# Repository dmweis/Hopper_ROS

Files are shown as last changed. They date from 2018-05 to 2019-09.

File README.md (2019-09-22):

# ROS stack for a hexapod robot

## [Click here for more images](https://davidweis.dev/robotics/2019/09/21/HopperGallery2019.html)  

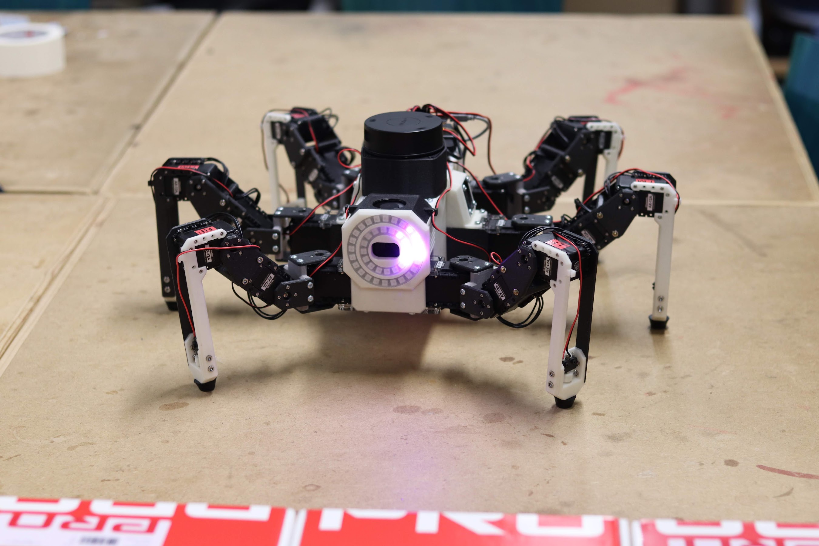
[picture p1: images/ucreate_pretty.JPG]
Hopper (https://davidweis.dev/robotics/2019/09/21/HopperGallery2019.html)
  

## [Click here to see live CAD model!](https://davidweis.dev/robotics/2019/06/22/HopperModels.html)  

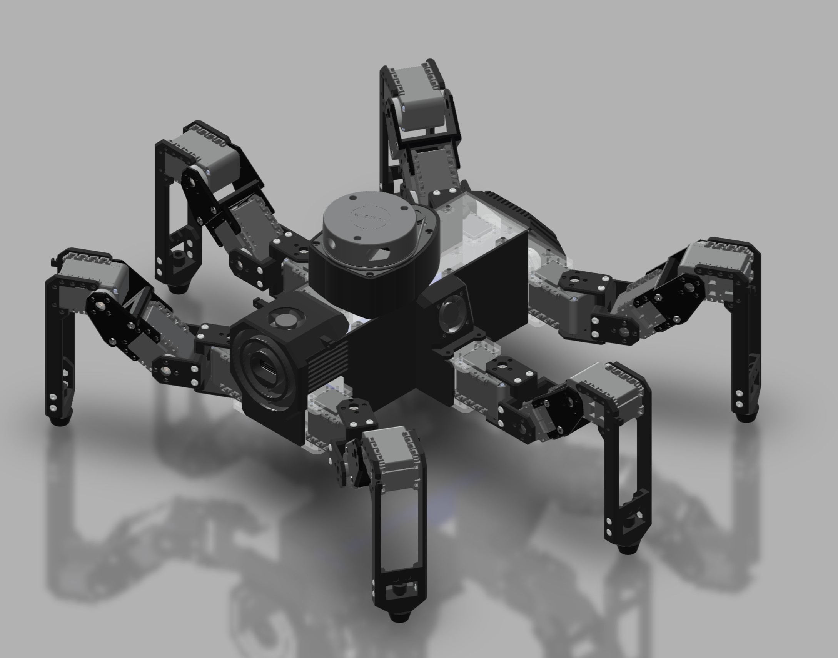
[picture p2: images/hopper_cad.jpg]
Cad model can be viewed here (https://davidweis.dev/robotics/2019/06/22/HopperModels.html)
  

## [Click here for videos](https://www.youtube.com/playlist?list=PL2rJqSX7Z5cFj5UM5ozf1wcm_McQg75ch)  

IMAGE ALT TEXT HERE (https://www.youtube.com/playlist?list=PL2rJqSX7Z5cFj5UM5ozf1wcm_McQg75ch)  

Hopper (Named after Grace Hopper) is a 3D printed hexapod robot running on ROS.
It's brain is a Raspberry Pi 3 running Ubunut Xenial with ROS Kinetic.
The platform is modeled and 3D printed by me and is still a work in progress. It's heavily inspired by [PhantomX Hexapod from Trossen robotics](http://www.trossenrobotics.com/phantomx-ax-hexapod.aspx)  

CAD design files can be found [here](https://github.com/dmweis/hopper_design)  
They may be outdated. If you'd like current file you can email me [here](mailto:dweis7@gmail.com)

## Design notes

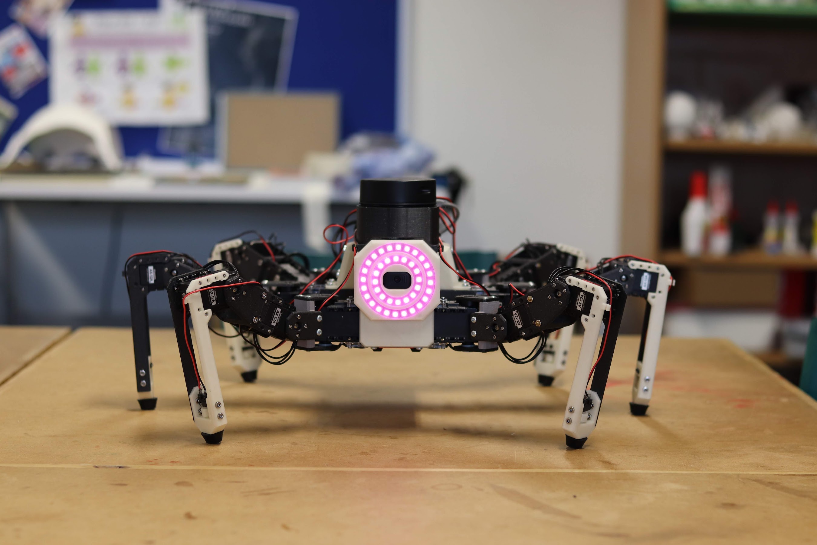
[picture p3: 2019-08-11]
images/ucreate_face.jpg

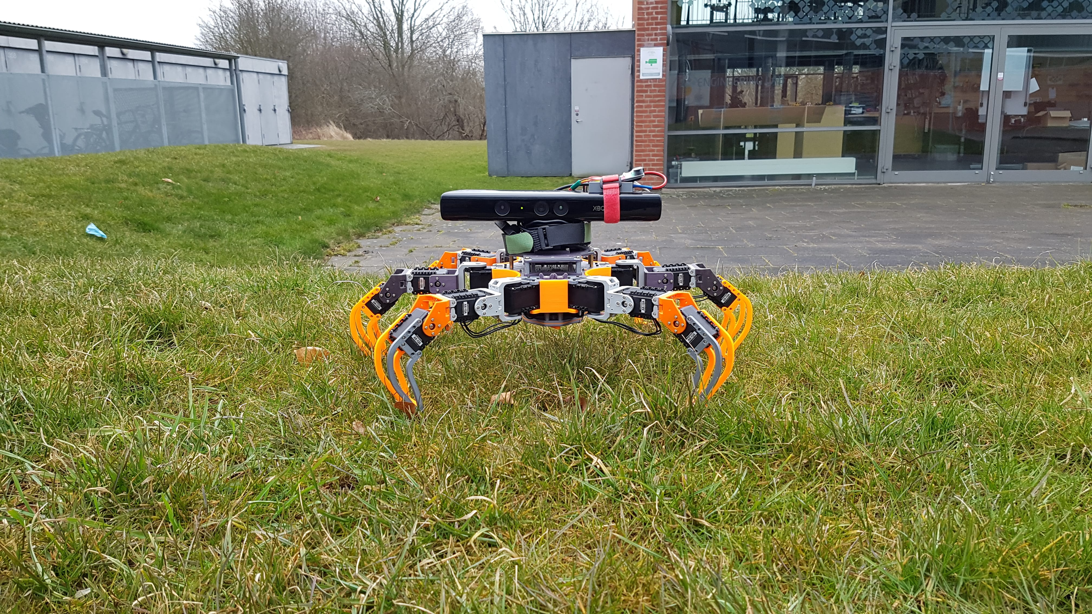
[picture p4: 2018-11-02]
images/grass_2.jpg

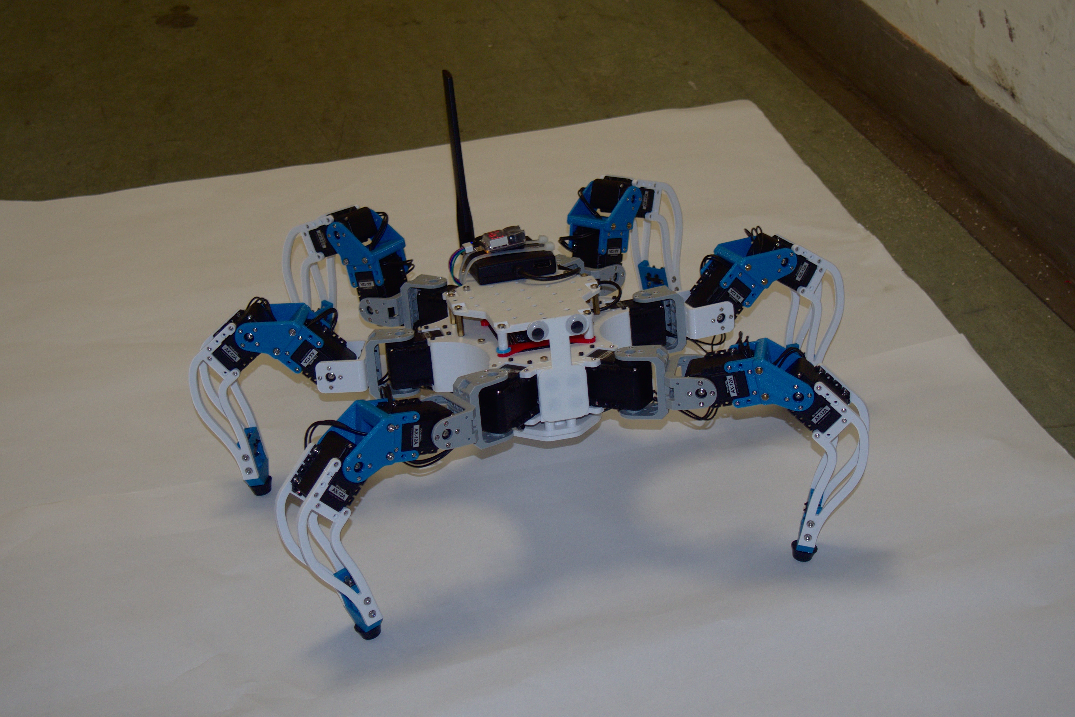
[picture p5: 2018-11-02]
images/last_2.jpg

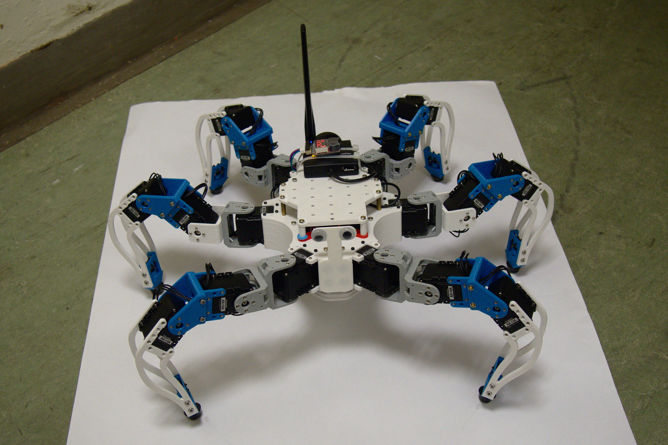
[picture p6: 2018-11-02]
images/last_1.jpg

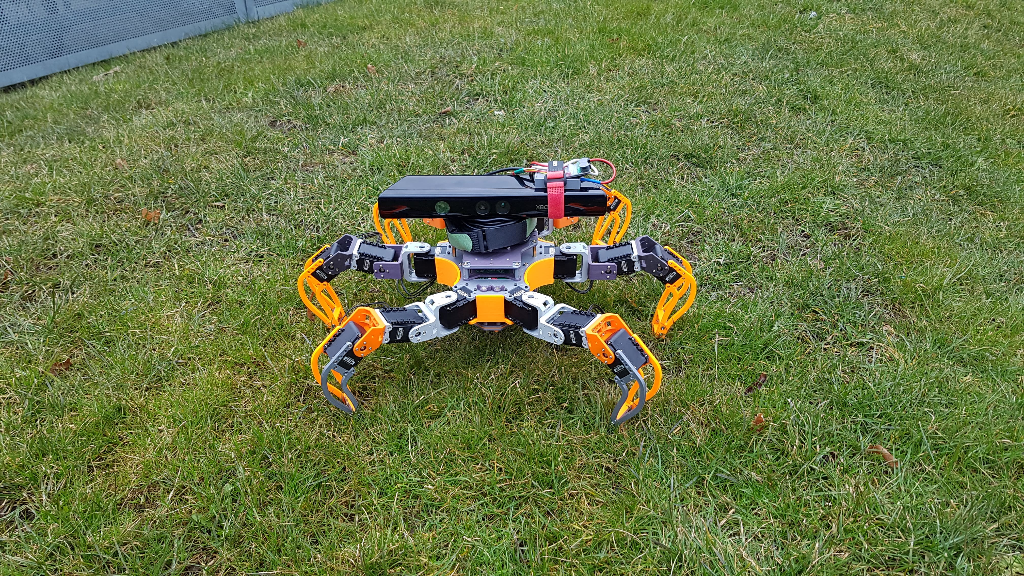
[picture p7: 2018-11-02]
images/grass_1.jpg

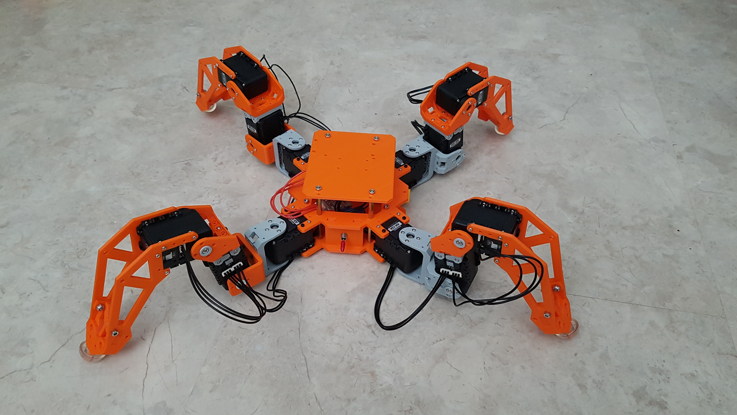
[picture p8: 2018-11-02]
images/quadruped.jpg

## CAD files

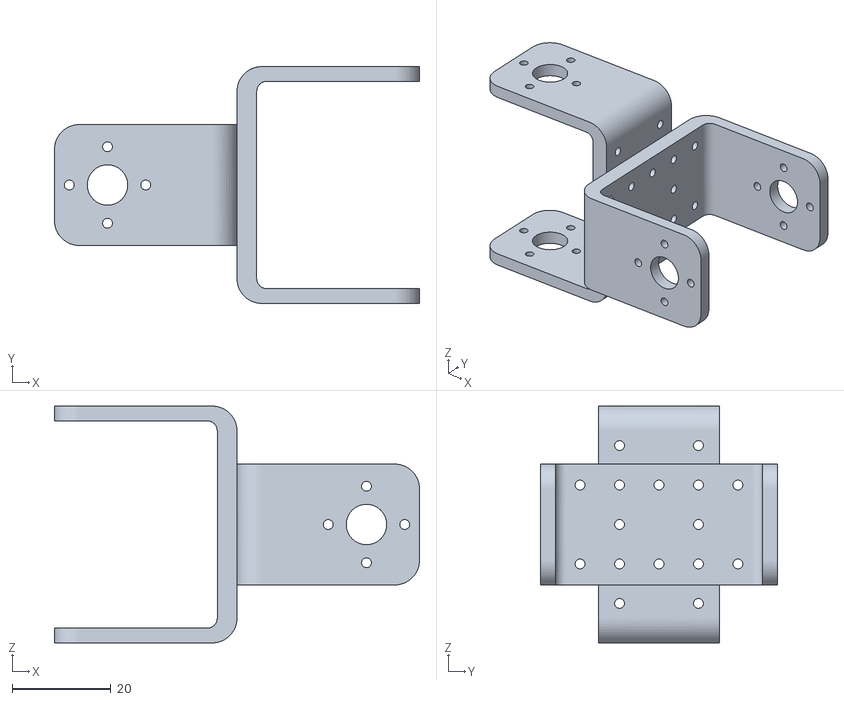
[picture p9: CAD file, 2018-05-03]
hopper_description/meshes/hopper_1/hopper_leg_coxa.stl
74.0 x 48.0 x 48.0

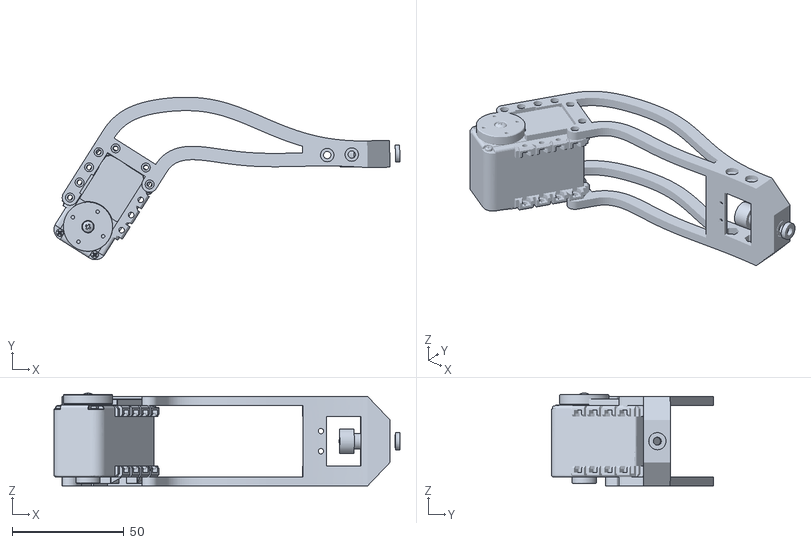
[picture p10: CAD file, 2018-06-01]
hopper_description/meshes/hopper_1/longer_legs/hopper_leg_tibia.stl
154.8 x 72.7 x 41.5

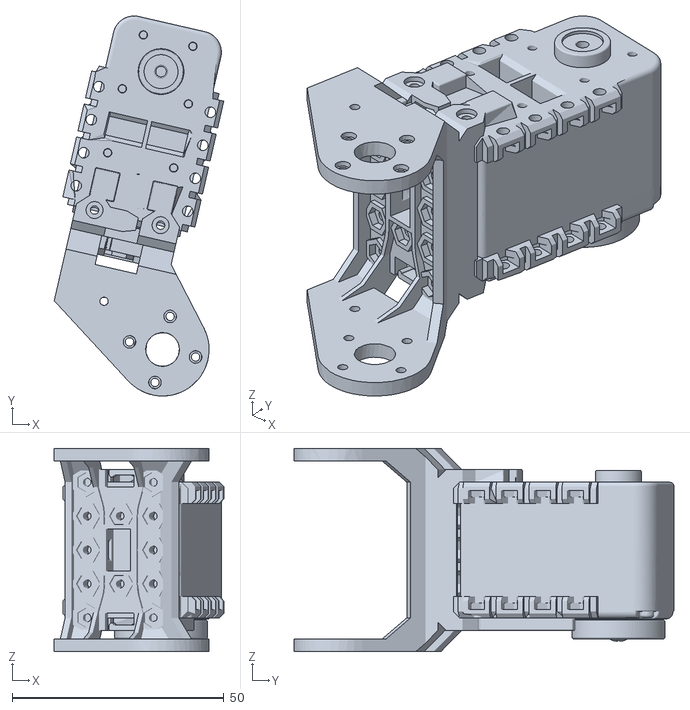
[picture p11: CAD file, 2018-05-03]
hopper_description/meshes/hopper_1/shorter_legs/hopper_leg_femur.stl
40.0 x 89.7 x 48.0

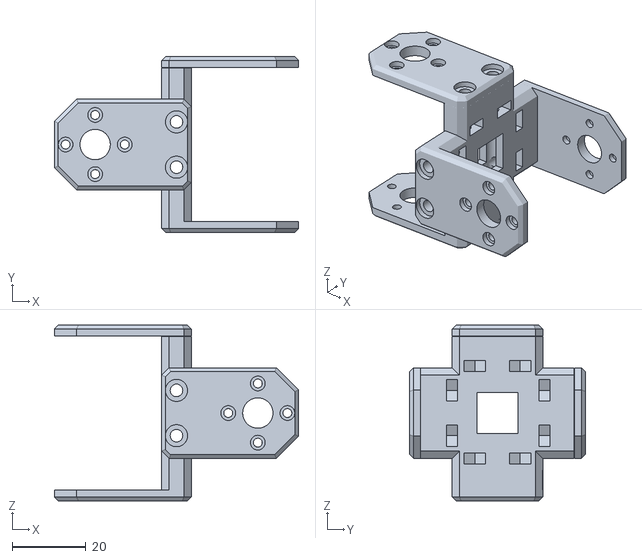
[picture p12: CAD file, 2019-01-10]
hopper_description/meshes/hopper_leg_coxa.stl
66.0 x 47.5 x 47.5

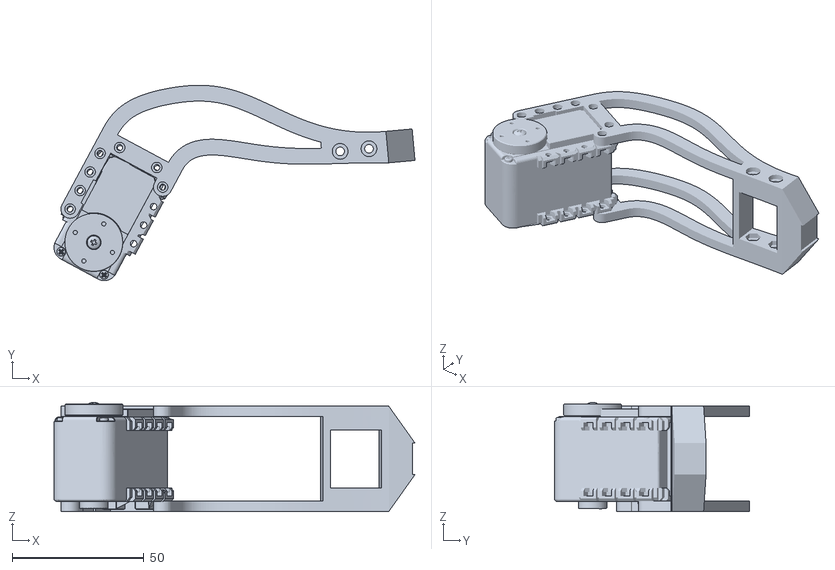
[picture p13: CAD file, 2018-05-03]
hopper_description/meshes/hopper_1/shorter_legs/hopper_leg_tibia.stl
137.1 x 74.2 x 41.4

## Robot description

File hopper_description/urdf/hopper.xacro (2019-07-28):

<?xml version="1.0"?>
<robot xmlns:xacro="http://ros.org/wiki/xacro" name="Hopper">
    <xacro:property name="coxa_length" value="0.044" />
    <xacro:property name="femur_length" value="0.07" />
    <xacro:property name="tibia_length" value="0.128" />
    <material name="white">
        <color rgba="1 1 1 1"/>
    </material>
    <material name="red">
        <color rgba="1 0 0 1"/>
    </material>
    <!-- main body -->
    <link name="base_link"/>
    <link name="body_link">
        <visual>
            <geometry>
                <mesh filename="package://hopper_description/meshes/hopper_body_full.stl" scale="0.001 0.001 0.001"/>
            </geometry>
            <material name="white"/>
        </visual>
    </link>
    <joint name="base_joint" type="fixed">
        <parent link="base_link" />
        <child link="body_link" />
    </joint>
    <!-- <link name="base_stabilized"/>
    <joint name="base_orientation_joint" type="fixed">
        <parent link="base_stabilized" />
        <child link="base_link" />
    </joint> -->
    <!-- forward arrow -->
    <link name="arrow">
        <visual>
            <geometry>
                <cylinder length="0.2" radius="0.01"/>
            </geometry>
            <material name="red"/>
            <origin xyz="0.1 0 0" rpy="0 ${pi/2} 0"/>
        </visual>
    </link>
    <joint name="arrow_joint" type="fixed">
        <parent link="base_link" />
        <child link="arrow" />
    </joint>
    <!-- laser attachment -->
    <link name="laser"/>
    <joint name="body_laser_joint" type="fixed">
        <parent link="body_link" />
        <child link="laser" />
        <origin xyz="0.035 0 0.112" rpy="0 0 ${pi}"/>
    </joint>
    <!-- IMU attachment -->
    <link name="imu"/>
    <joint name="body_imu_joint" type="fixed">
        <parent link="body_link" />
        <child link="imu" />
        <origin xyz="0.025 0 0" rpy="${pi} 0 ${pi}"/>
    </joint>
    <!-- Stereo camera  -->
    <!-- <link name="stereo_camera"/>
    <joint name="body_camera_joint" type="fixed">
        <parent link="body_link" />
        <child link="stereo_camera" />
        <origin xyz="0.025 0 0.11" />
    </joint>
    <link name="left_camera"/>
    <link name="right_camera"/>
    <joint name="camera_left_joint" type="fixed">
        <parent link="stereo_camera" />
        <child link="left_camera" />
        <origin xyz="0 0.07 0" rpy="0 ${pi/2} 0" />
    </joint>
    <joint name="camera_right_joint" type="fixed">
        <parent link="stereo_camera" />
        <child link="right_camera" />
        <origin xyz="0 -0.07 0" rpy="0 ${pi/2} 0" />
    </joint> -->
    <!-- xacro macro for leg -->
    <xacro:macro name="leg" params="side position x y angle axis">
        <!-- leg base -->
        <link name="${side}_${position}_leg_base"/>
        <joint name="${side}_${position}_leg_base_joint" type="fixed">
            <origin xyz="${x} ${y} 0.0" rpy="0.0 0.0 0.0" />
            <parent link="body_link" />
            <child link="${side}_${position}_leg_base" />
        </joint>
        <!-- coxa -->
        <link name="${side}_${position}_coxa">
            <visual>
                <geometry>
                    <mesh filename="package://hopper_description/meshes/hopper_leg_coxa.stl" scale="0.001 0.001 0.001"/>
                </geometry>
                <material name="white"/>
            </visual>
        </link>
        <joint name="${side}_${position}_coxa_joint" type="revolute">
            <origin xyz="0.0 0.0 0.0" rpy="0.0 0.0 ${angle}" />
            <parent link="${side}_${position}_leg_base" />
            <child link="${side}_${position}_coxa" />
            <axis xyz="0.0 0.0 1.0" />
            <limit lower="-${pi}" upper="${pi}" effort="1000.0" velocity="1"/>
        </joint>
        <!-- femur -->
        <link name="${side}_${position}_femur">
            <visual>
                <geometry>
                    <mesh filename="package://hopper_description/meshes/hopper_leg_femur.stl" scale="0.001 0.001 0.001"/>
                </geometry>
                <material name="white"/>
            </visual>
        </link>
        <joint name="${side}_${position}_femur_joint" type="revolute">
            <origin xyz="${coxa_length} 0.0 0.0" rpy="-${pi/2} ${pi/2} 0.0" />
            <parent link="${side}_${position}_coxa" />
            <child link="${side}_${position}_femur" />
            <axis xyz="0.0 0.0 ${-axis}" />
            <limit lower="-${pi}" upper="${pi}" effort="1000.0" velocity="1"/>
        </joint>
        <!-- tibia -->
        <link name="${side}_${position}_tibia">
            <visual>
                <geometry>
                    <mesh filename="package://hopper_description/meshes/hopper_leg_tibia.stl" scale="0.001 0.001 0.001"/>
                </geometry>
                <material name="white"/>
            </visual>
        </link>
        <joint name="${side}_${position}_tibia_joint" type="revolute">
            <origin xyz="0.0 -${femur_length} 0.0" rpy="${pi} 0.0 0.0" />
            <parent link="${side}_${position}_femur" />
            <child link="${side}_${position}_tibia" />
            <axis xyz="0.0 0.0 ${axis}" />
            <limit lower="-${pi}" upper="${pi}" effort="1000.0" velocity="1"/>
        </joint>
        <link name="${side}_${position}_button"/>
        <joint name="${side}_${position}_tibia_button" type="fixed">
            <origin xyz="${tibia_length} 0.0 0.0"/>
            <parent link="${side}_${position}_tibia" />
            <child link="${side}_${position}_button" />
        </joint>
    </xacro:macro>
    <!--build legs-->
    <xacro:leg side="right" position="rear" x="-0.115" y="-0.063" angle="-${pi/2}" axis="1" />
    <xacro:leg side="right" position="middle" x="0.0" y="-0.103" angle="-${pi/2}" axis="1" />
    <xacro:leg side="right" position="front" x="0.115" y="-0.063" angle="-${pi/2}" axis="1" />
    <xacro:leg side="left" position="rear" x="-0.115" y="0.063" angle="${pi/2}" axis="-1" />
    <xacro:leg side="left" position="middle" x="0.0" y="0.103" angle="${pi/2}" axis="-1" />
    <xacro:leg side="left" position="front" x="0.115" y="0.063" angle="${pi/2}" axis="-1" />
</robot>

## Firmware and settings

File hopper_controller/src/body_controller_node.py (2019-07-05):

#!/usr/bin/env python

from threading import Lock
import rospy

from hopper_msgs.msg import ServoTelemetry, HexapodTelemetry
from hopper_controller.msg import HexapodMotorPositions, LegMotorPositions, MotorCompliance, MotorSpeed, MotorTorque
from hopper_controller.srv import ReadHexapodMotorPositions, ReadHexapodMotorPositionsResponse
from dynamixel import DynamixelDriver, search_usb_2_ax_port
from ros_abstraction import JointStatePublisher, MessagePublisher


class BodyMotorController(object):
    def __init__(self):
        super(BodyMotorController, self).__init__()
        rospy.init_node('hopper_body_controller')
        self.driver_lock = Lock()
        self.leg_data = rospy.get_param("legs")
        self.servo_ids = []
        for leg in self.leg_data:
            self.servo_ids.append(self.leg_data[leg]["coxa_id"])
            self.servo_ids.append(self.leg_data[leg]["femur_id"])
            self.servo_ids.append(self.leg_data[leg]["tibia_id"])
        self.servo_driver = DynamixelDriver(search_usb_2_ax_port())
        self.message_publisher = MessagePublisher()
        self.joint_state_publisher = JointStatePublisher(self.message_publisher)
        rospy.Subscriber("hopper/body/motor_command", HexapodMotorPositions, self.on_motor_command, queue_size=20)
        rospy.Subscriber("hopper/body/motor_compliance", MotorCompliance, self.on_compliance_command, queue_size=25)
        rospy.Subscriber("hopper/body/motor_speed", MotorSpeed, self.on_speed_command, queue_size=5)
        rospy.Subscriber("hopper/body/motor_torque", MotorTorque, self.on_torque_command, queue_size=20)
        self.body_motor_positions_service = rospy.Service("hopper/read_hexapod_motor_positions", ReadHexapodMotorPositions, self.read_hexapod_motor_positions)
        self.telementrics_publisher = rospy.Publisher('hopper_telemetry', HexapodTelemetry, queue_size=5)
        telemetry_update_interval = rospy.Duration.from_sec(0.1)
        self.telemetry_motor_id_index = 0
        while not rospy.is_shutdown():
            rospy.sleep(telemetry_update_interval)
            try:
                self.read_motor_telemetry()
            except IOError as e:
                rospy.logerr("IOError on telemetry read " + str(e))
        with self.driver_lock:
            for servo_id in self.servo_ids:
                self.servo_driver.set_torque(servo_id, False)
            self.servo_driver.close()

    def on_motor_command(self, msg):
        commands = [
            # left front
            (self.leg_data["left_front"]["coxa_id"], msg.left_front.coxa),
            (self.leg_data["left_front"]["femur_id"], msg.left_front.femur),
            (self.leg_data["left_front"]["tibia_id"], msg.left_front.tibia),
            # right front
            (self.leg_data["right_front"]["coxa_id"], msg.right_front.coxa),
            (self.leg_data["right_front"]["femur_id"], msg.right_front.femur),
            (self.leg_data["right_front"]["tibia_id"], msg.right_front.tibia),
            # left middle
            (self.leg_data["left_middle"]["coxa_id"], msg.left_middle.coxa),
            (self.leg_data["left_middle"]["femur_id"], msg.left_middle.femur),
            (self.leg_data["left_middle"]["tibia_id"], msg.left_middle.tibia),
            # right middle
            (self.leg_data["right_middle"]["coxa_id"], msg.right_middle.coxa),
            (self.leg_data["right_middle"]["femur_id"], msg.right_middle.femur),
            (self.leg_data["right_middle"]["tibia_id"], msg.right_middle.tibia),
            # left rear
            (self.leg_data["left_rear"]["coxa_id"], msg.left_rear.coxa),
            (self.leg_data["left_rear"]["femur_id"], msg.left_rear.femur),
            (self.leg_data["left_rear"]["tibia_id"], msg.left_rear.tibia),
            # right rear
            (self.leg_data["right_rear"]["coxa_id"], msg.right_rear.coxa),
            (self.leg_data["right_rear"]["femur_id"], msg.right_rear.femur),
            (self.leg_data["right_rear"]["tibia_id"], msg.right_rear.tibia)
        ]
        with self.driver_lock:
            self.servo_driver.group_sync_write_goal_degrees(commands)
        self.joint_state_publisher.update_joint_states(msg)

    def on_compliance_command(self, command):
        with self.driver_lock:
            for servo_id in self.servo_ids:
                self.servo_driver.set_compliance_slope(servo_id, command.compliance)

    def on_speed_command(self, command):
        with self.driver_lock:
            for servo_id in self.servo_ids:
                self.servo_driver.set_moving_speed(servo_id, command.speed)

    def on_torque_command(self, command):
        with self.driver_lock:
            for servo_id in self.servo_ids:
                self.servo_driver.set_torque(servo_id, command.torque)

    def read_hexapod_motor_positions(self, _):
        def read_pos(servo_id):
            return self.servo_driver.read_current_position_degrees(servo_id)

        def read_leg(leg_config):
            return LegMotorPositions(
                read_pos(leg_config["coxa_id"]),
                read_pos(leg_config["femur_id"]),
                read_pos(leg_config["tibia_id"])
            )
        msg = HexapodMotorPositions()
        with self.driver_lock:
            msg.left_front = read_leg(self.leg_data["left_front"])
            msg.right_front = read_leg(self.leg_data["right_front"])
            msg.left_middle = read_leg(self.leg_data["left_middle"])
            msg.right_middle = read_leg(self.leg_data["right_middle"])
            msg.left_rear = read_leg(self.leg_data["left_rear"])
            msg.right_rear = read_leg(self.leg_data["right_rear"])
        return ReadHexapodMotorPositionsResponse(msg)

    def read_motor_telemetry(self):
        robot_telemetry = HexapodTelemetry()
        with self.driver_lock:
            servo_id = self.servo_ids[self.telemetry_motor_id_index]
            voltage = self.servo_driver.read_voltage(servo_id)
            temperature = self.servo_driver.read_temperature(servo_id)
            robot_telemetry.servos.append(ServoTelemetry(servo_id, temperature, voltage))
        self.telemetry_motor_id_index += 1
        if self.telemetry_motor_id_index > len(self.servo_ids) - 1:
            self.telemetry_motor_id_index = 0
        self.telementrics_publisher.publish(robot_telemetry)


if __name__ == '__main__':
    BodyMotorController()

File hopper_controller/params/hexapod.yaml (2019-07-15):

coxa_length: 4.4
femur_length: 7
tibia_length: 12.8

femur_offset: 4.9
tibia_offset: 73.8

legs:
  left_front:
    coxa_id: 1
    femur_id: 3
    tibia_id: 5
    angle_offset: -90
    position:
      x: 11.5
      y: 6.3
      z: 0
    femur_correction: -240
    tibia_correction: -330
  right_front:
    coxa_id: 2
    femur_id: 4
    tibia_id: 6
    angle_offset: 90
    position:
      x: 11.5
      y: -6.3
      z: 0
    femur_correction: 60
    tibia_correction: -30
  left_middle:
    coxa_id: 13
    femur_id: 15
    tibia_id: 17
    angle_offset: -90
    position:
      x: 0
      y: 10.3
      z: 0
    femur_correction: -240
    tibia_correction: -330
  right_middle:
    coxa_id: 14
    femur_id: 16
    tibia_id: 18
    angle_offset: 90
    position:
      x: 0
      y: -10.3
      z: 0
    femur_correction: 60
    tibia_correction: -30
  left_rear:
    coxa_id: 7
    femur_id: 9
    tibia_id: 11
    angle_offset: -90
    position:
      x: -11.5
      y: 6.3
      z: 0
    femur_correction: -240
    tibia_correction: -330
  right_rear:
    coxa_id: 8
    femur_id: 10
    tibia_id: 12
    angle_offset: 90
    position:
      x: -11.5
      y: -6.3
      z: 0
    femur_correction: 60
    tibia_correction: -30

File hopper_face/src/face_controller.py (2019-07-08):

#!/usr/bin/env python

from __future__ import print_function, division

from threading import Thread
import serial
import random
import rospy
import tf2_ros

from cobs import cobs
from colorsys import hsv_to_rgb, rgb_to_hsv
from rospy import sleep
from std_msgs.msg import String, Bool
from sensor_msgs.msg import Imu
from geometry_msgs.msg import TransformStamped

PIXEL_COUNT = 40

PIXELS_ON_BIGGER_RING = 24
PIXELS_ON_SMALLER_RING = 16

BIGGER_TOP_INDEX = 7
BIGGER_BOTTOM_INDEX = 19
SMALLER_TOP_INDEX = 35
SMALLER_BOTTOM_INDEX = 27


def map_linear(value, in_min, in_max, out_min, out_max):
    return (value - in_min) * (out_max - out_min) / (in_max - in_min) + out_min


def clamp(value, a, b):
    min_value = min(a, b)
    max_value = max(a, b)
    return max(min(max_value, value), min_value)


class Color(object):
    def __init__(self, red=0, green=0, blue=0, name=None):
        super(Color, self).__init__()
        self.red = red
        self.green = green
        self.blue = blue
        if name is not None:
            web_color = webcolors.name_to_rgb(name)
            self.red = web_color.red
            self.green = web_color.green
            self.blue = web_color.blue

    def faded_out(self, reduce_by):
        h, s, v = self.to_hsv()
        v = v - v*reduce_by
        v = clamp(v, 0.0, 1.0)
        return HsvColor(h, s, v)

    def to_data(self):
        return [self.red, self.green, self.blue]

    def to_hsv(self):
        red = map_linear(self.red, 0, 255, 0, 1.0)
        green = map_linear(self.green, 0, 255, 0, 1.0)
        blue = map_linear(self.blue, 0, 255, 0, 1.0)
        return rgb_to_hsv(red, green, blue)

    def clone(self):
        return Color(self.red, self.green, self.blue)


class HsvColor(Color):
    def __init__(self, h, s, v):
        red, green, blue = hsv_to_rgb(h, s, v)
        red = int(red * 255)
        green = int(green * 255)
        blue = int(blue * 255)
        super(HsvColor, self).__init__(red, green, blue)


class ColorPacket():
    def __init__(self, from_color=None):
        if from_color is not None:
            self.data = from_color.to_data() * PIXEL_COUNT
        else:
            self.data = Color().to_data() * PIXEL_COUNT

    def correct_pixel_index(self, index):
        index %= PIXEL_COUNT

        if index >= PIXELS_ON_BIGGER_RING:
            index_on_smaller = index - PIXELS_ON_BIGGER_RING
            final_index = PIXELS_ON_SMALLER_RING - 1 - index_on_smaller + PIXELS_ON_BIGGER_RING
            return final_index
        return index

    def set_pixel(self, index, color):
        index = self.correct_pixel_index(index)
        self.data[index * 3] = color.red
        self.data[index * 3 + 1] = color.green
        self.data[index * 3 + 2] = color.blue

    def get_pixel(self, index):
        index = self.correct_pixel_index(index)
        color = Color()
        color.red = self.data[index * 3]
        color.green = self.data[index * 3 + 1]
        color.blue = self.data[index * 3 + 2]
        return color

    def fade_out(self, reduce_by):
        for index in range(PIXEL_COUNT):
            pixel = self.get_pixel(index).faded_out(reduce_by)
            self.set_pixel(index, pixel)

    def to_data(self):
        return cobs.encode(bytes(bytearray(self.data))) + bytes(bytearray([0]))


COLORS = {
    "red": Color(10, 0, 0),
    "blue": Color(0, 0, 10),
    "green": Color(0, 10, 0),
    "yellow": Color(10, 10, 0),
    "purple": Color(10, 0, 10)
}

BRIGHT_COLORS = {
    "red": Color(180, 0, 0),
    "blue": Color(0, 0, 180),
    "green": Color(0, 180, 0),
    "yellow": Color(100, 100, 0),
    "purple": Color(100, 0, 100)
}


class LedController(object):
    def __init__(self):
        super(LedController, self).__init__()
        rospy.init_node("face_controller")
        self.port = None
        self.selected_mode = ""
        self.selected_color = ""
        self.is_active = True
        self.modes = {}
        rospy.Subscriber("hopper/face/mode", String,
                         self.on_mode_change, queue_size=3)
        rospy.Subscriber("hopper/face/active", Bool, self.on_active_msg, queue_size=10)
        # controller ready system
        self.controller_ready = False
        rospy.Subscriber("hopper/main_controller_ready", Bool, self.on_ready_msg, queue_size=2)
        # IMU
        self.imu_publisher = rospy.Publisher("hopper/imu/data", Imu, queue_size=10)

    def on_mode_change(self, msg):
        new_mode = msg.data.lower()
        # special case for random
        if new_mode == "random":
            self.selected_color = random.choice(list(COLORS))
            self.selected_mode = random.choice(list(self.modes))
            return
        if ":" in new_mode:
            mode, color = new_mode.split(":")
            if color in COLORS:
                self.selected_color = color
            else:
                rospy.logwarn("Color: " + color + " unknown")
            new_mode = mode
        if new_mode in self.modes:
            self.selected_mode = new_mode
        else:
            rospy.logwarn("Mode: " + new_mode + " unknown")

    def on_active_msg(self, active_msg):
        self.is_active = active_msg.data

    def write(self, frame):
        self.port.write(frame.to_data())

    def reset(self):
        self.port.write(ColorPacket().to_data())

    def read_loop(self):
        transform_broadcaster = tf2_ros.TransformBroadcaster()
        while not rospy.is_shutdown():
            line = self.port.readline()
            data = line.split(',')
            if len(data) != 14:
                continue
            imu_msg = Imu()
            imu_msg.header.frame_id = "imu"
            imu_msg.header.stamp = rospy.Time.now()
            imu_msg.orientation.x = float(data[0])
            imu_msg.orientation.y = float(data[1])
            imu_msg.orientation.z = float(data[2])
            imu_msg.orientation.w = float(data[3])
            imu_msg.orientation_covariance[0] = -1

            imu_msg.linear_acceleration.x = float(data[4])
            imu_msg.linear_acceleration.y = float(data[5])
            imu_msg.linear_acceleration.z = float(data[6])
            imu_msg.linear_acceleration_covariance[0] = -1

            imu_msg.angular_velocity.x = float(data[7])
            imu_msg.angular_velocity.y = float(data[8])
            imu_msg.angular_velocity.z = float(data[9])
            imu_msg.angular_velocity_covariance[0] = -1
            self.imu_publisher.publish(imu_msg)
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

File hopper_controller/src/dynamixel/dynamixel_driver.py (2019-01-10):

from __future__ import division
import dynamixel_functions as dynamixel
from dynamixel_error_helper import get_rx_pack_error_description, get_tx_rx_result_description
import serial.tools.list_ports

# Control table address for protocol 1
ID = 3
CW_ANGLE_LIMIT = 6
CCW_ANGLE_LIMIT = 8
TORQUE_ENABLE = 24
LED_ENABLE = 25
CW_COMPLIANCE_MARGIN = 26
CCW_COMPLIANCE_MARGIN = 27
CW_COMPLIANCE_SLOPE = 28
CCW_COMPLIANCE_SLOPE = 29
GOAL_POSITION = 30
MOVING_SPEED = 32
TORQUE_LIMIT = 34
PRESENT_POSITION = 36
PRESENT_SPEED = 38
PRESENT_LOAD = 40
PRESENT_VOLTAGE = 42
PRESENT_TEMP = 43
PRESENT_MOVING = 46

PROTOCOL = 1


def search_usb_2_ax_port():
    ports = list(serial.tools.list_ports.comports())
    dynamixel_port = next(port for port in ports if "USB2AX" in port.description)
    return dynamixel_port.device


def map_linear(value, in_min, in_max, out_min, out_max):
    return (value - in_min) * (out_max - out_min) / (in_max - in_min) + out_min


def clamp(value, min_value, max_value):
    return max(min(max_value, value), min_value)


def degrees_to_dynamixel_units(degrees):
    return round(clamp(map_linear(degrees, 0, 300, 0, 1023), 0, 1023))


def dynamixel_units_to_degrees(units):
    return round(clamp(map_linear(units, 0, 1023, 0, 300), 0, 300))


class DynamixelDriver(object):
    def __init__(self, port_name):
        self.__port_num = dynamixel.portHandler(port_name.encode('utf-8'))
        dynamixel.packetHandler()
        if not dynamixel.openPort(self.__port_num):
            raise IOError("Failed to open port")
        if not dynamixel.setBaudRate(self.__port_num, 1000000):
            raise IOError("Failed to set baud rate")

    def ping(self, servo_id):
        dynamixel.ping(self.__port_num, PROTOCOL, servo_id)
        dxl_comm_result = dynamixel.getLastTxRxResult(self.__port_num, 1)
        dxl_error = dynamixel.getLastRxPacketError(self.__port_num, 1)
        if dxl_comm_result != 0:
            return False
        if dxl_error != 0:
            error_desciption = get_rx_pack_error_description(dxl_error)
            raise IOError("dxl_error: " + error_desciption)
        return True

    def search_servos(self, start_id=0, end_id=252):
        found_servos = []
        for servo_id in range(start_id, end_id + 1):
            if self.ping(servo_id):
                found_servos.append(servo_id)
        return found_servos

    def set_id(self, servo_id, new_servo_id):
        if self.ping(new_servo_id):
            raise IOError("New Id already taken")
        self.__write_byte(servo_id, ID, new_servo_id)

    def set_led(self, servo_id, status):
        """

        :type servo_id: int
        :type status: bool
        """
        self.__write_byte(servo_id, LED_ENABLE, int(status))

    def set_goal_position(self, servo_id, goal_position):
        self.__write_uint_16(servo_id, GOAL_POSITION, goal_position)

    def set_torque(self, servo_id, value):
        self.__write_byte(servo_id, TORQUE_ENABLE, int(value))

    def read_current_position(self, servo_id):
        return self.__read_uint_16(servo_id, PRESENT_POSITION)

    def read_current_position_degrees(self, servo_id):
        return dynamixel_units_to_degrees(self.read_current_position(servo_id))

    def set_moving_speed(self, servo_id, moving_speed, cw=False):
        if cw:
            moving_speed |= 1 >> 10
        self.__write_uint_16(servo_id, MOVING_SPEED, moving_speed)

    def read_voltage(self, servo_id):
        return self.__read_byte(servo_id, PRESENT_VOLTAGE) / 10.0

    def read_temperature(self, servo_id):
        return self.__read_byte(servo_id, PRESENT_TEMP)

    def read_present_load(self, servo_id):
        load_data = self.__read_uint_16(servo_id, PRESENT_LOAD)
        ccw = bool(load_data & 1 << 10)
        load = (load_data & ~(1 << 10)) / 10
        return -load if ccw else load

    def set_ccw_max_angle_limit(self, servo_id, max_angle):
        self.__write_uint_16(servo_id, CCW_ANGLE_LIMIT, max_angle)

    def set_cw_min_angle_limit(self, servo_id, min_angle):
        self.__write_uint_16(servo_id, CW_ANGLE_LIMIT, min_angle)

    def read_angle_limits(self, servo_id):
        max_angle = self.__read_uint_16(servo_id, CCW_ANGLE_LIMIT)
        min_angle = self.__read_uint_16(servo_id, CW_ANGLE_LIMIT)
        return min_angle, max_angle

    def read_torque_limit(self, servo_id):
        return self.__read_uint_16(servo_id, TORQUE_LIMIT)

    def group_sync_write_goal_degrees(self, commands):
        commands = map(lambda command: (command[0], degrees_to_dynamixel_units(command[1])), commands)
        self.group_sync_write_goal(commands)

    def group_sync_write_goal(self, commands):
        sync_group_num = dynamixel.groupSyncWrite(self.__port_num, PROTOCOL, GOAL_POSITION, 2)
        for servo_id, goal_position in commands:
            success = dynamixel.groupSyncWriteAddParam(sync_group_num, servo_id, int(goal_position), 2)
            if not success:
                raise IOError("failed writing to group sync write")
        dynamixel.groupSyncWriteTxPacket(sync_group_num)
        dxl_comm_result = dynamixel.getLastTxRxResult(self.__port_num, PROTOCOL)
        if dxl_comm_result != 0:
            error_desciption = get_tx_rx_result_description(dxl_comm_result)
            raise IOError("dxl_comm_result: " + error_desciption)
        dynamixel.groupSyncWriteClearParam(sync_group_num)

    def set_compliance_slope(self, servo_id, compliance_slope):
        self.__write_byte(servo_id, CW_COMPLIANCE_SLOPE, compliance_slope)
        self.__write_byte(servo_id, CCW_COMPLIANCE_SLOPE, compliance_slope)

    def read_compliance_slope(self, servo_id):
        cw = self.__read_byte(servo_id, CW_COMPLIANCE_SLOPE)
        ccw = self.__read_byte(servo_id, CCW_COMPLIANCE_SLOPE)
        return cw, ccw

    def read_compliance_margin(self, servo_id):
        cw = self.__read_byte(servo_id, CW_COMPLIANCE_MARGIN)
        ccw = self.__read_byte(servo_id, CCW_COMPLIANCE_MARGIN)
        return cw, ccw

    def __write_uint_16(self, servo_id, address, data):
        dynamixel.write2ByteTxRx(self.__port_num, PROTOCOL, servo_id, address, data)
        self.__verify_last_message()

    def __write_byte(self, servo_id, address, data):
        dynamixel.write1ByteTxRx(self.__port_num, PROTOCOL, servo_id, address, data)
        self.__verify_last_message()

    def __read_uint_16(self, servo_id, address):
        incoming = dynamixel.read2ByteTxRx(self.__port_num, PROTOCOL, servo_id, address)
        self.__verify_last_message()
        return incoming

    def __read_byte(self, servo_id, address):
        incoming = dynamixel.read1ByteTxRx(self.__port_num, PROTOCOL, servo_id, address)
        self.__verify_last_message()
        return incoming
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

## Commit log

2018-01-25 Fix robot not rotating because rotattion is not updated
    [quadruped_controller.py]
2018-02-02 Add rotation support and condition torque disabling
2018-02-02 Add ability to return hexapod legs to relaxed position after walking
2018-02-03 Fix code standard violations and typos
    [hexapod_ik_driver.py]
2018-02-05 Update rotation speed and stand up and down sequence so the robot won't drags it's feet
    [hexapod_gait_engine.py]
2018-02-05 fix incorrectly set height for sit down position
    [hexapod_gait_engine.py]
2018-02-06 Fix switched rotation axis
2018-02-06 Update view to fit mobile devices
2018-02-08 Make socketio always use websockets and ignore long polling to speed up initial connection
2018-02-19 Add sonar web project
2018-02-21 Update to new sonar system
2018-02-21 Correct left and right switched motors
2018-02-22 Add python sonar driver
2018-02-27 Add catch for ik failures
    [hexapod_gait_engine.py]
2018-02-27 Add catching for aritmetic errors
    [hexapod_gait_engine.py]
2018-02-27 Add log to fatal death on ik error
    [hexapod_gait_engine.py]
2018-02-27 Fix log message format
    [hexapod_gait_engine.py]
2018-03-09 Add log in case of a crash
    [hexapod_gait_engine.py]
2018-03-09 Fix spacing between classes
    [hexapod_gait_engine.py]
2018-03-09 Fix reference pointing to instace variable insted of local
    [hexapod_gait_engine.py]
2018-03-09 Increase framerate of face detection
2018-03-09 Switch order of sleep and telemetrics check and add comments
2018-03-09 Update choreography for one leg only
2018-03-09 Fix error with passing message insted of text and add default fallback
    [hexapod_controller.py]
2018-03-10 Move leg furthure away for wave
2018-03-10 Adjust lifted leg wave position
2018-03-23 Decrease face detection framerate
2018-04-13 Add ping, searching, id setting and led setting to dyanmixel driver
2018-04-13 Add script for configuring servo ids
2018-04-13 Add print out for all IDs after shuffle
2018-04-13 UPdate print out and make sure id 18 is not taken
2018-04-14 Make sure hexapod legs will never try to go under ground level during walking
2018-04-14 Also update leg lift height for static mode
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2018-04-19 MOve each leg to it's target instead of along an axis
2018-04-19 Revert to better distance calculations
    [hexapod_gait_engine.py]
2018-04-19 Fix each step restarting initial position
    [hexapod_gait_engine.py]
2018-04-19 don't hold feet height in state to prevent leg shaking
    [hexapod_gait_engine.py]
2018-04-19 fix robot not moving because move condition was inverted
    [hexapod_gait_engine.py]
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2018-04-19 Make sure battery warning is only issued once
2018-04-22 Add description project
    [hopper.urdf]
2018-04-22 Add xacro depend and fix xml
    [hopper.urdf]
2018-04-22 UPdate scale since STL is in mm but ROS takes them as meters
    [hopper.urdf]
2018-04-22 Add meshes
    [hopper_leg_coxa.stl, hopper_leg_femur.stl, hopper_leg_tibia.stl]
2018-04-22 Fix orientation in udrf files
    [hopper.urdf]
2018-04-22 Add simple urdf description
    [hopper.urdf]
2018-04-22 Update offset for hopper body stl
    [hopper.urdf]
2018-04-22 Remove whitespace
    [hopper.urdf]
2018-04-22 center meshes
    [hopper_leg_coxa.stl, hopper_leg_femur.stl, hopper_leg_tibia.stl]
2018-04-23 Use xarco file with macros for limbs
    [hopper.urdf]
2018-04-23 Move stls to correct center and orientation
    [hopper_leg_femur.stl, hopper_leg_tibia.stl]
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2018-04-23 center stls vertically
    [hopper_leg_coxa.stl, hopper_leg_femur.stl, hopper_leg_tibia.stl]
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2018-04-23 fix typo in left front tibia
    [hexapod_ik_driver.py]
2018-04-23 fix femur offset for right side
    [hexapod_ik_driver.py]
2018-04-23 add tibia correction offset
    [hexapod_ik_driver.py]
2018-04-23 correct tibia offset for left
    [hexapod_ik_driver.py]
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2018-04-28 Create publisher for tf and joint state changes that updates at a set frequency
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2018-05-01 Add node for reading IMU data and arduino firmware
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2018-05-06 Rename forward and backwards legs to lifted and grounded
2018-05-06 Fix wrong button for turbo
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2018-05-06 Add reset relaxed pose to gait engine
    [hexapod_gait_engine.py]
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2018-05-06 Fix name for get relaxed pose
    [hexapod_gait_engine.py]
2018-05-06 Turn laser around to rotate it the correct way
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2018-05-06 Fix battery monitor to prevent repeating messages after restarts
2018-05-07 Fix orientation for lidar
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2018-05-09 Fix height estimation to take the 3 highest legs
    [hexapod_gait_engine.py]
2018-05-09 Fix passing result insted of method
    [hexapod_controller.py]
2018-05-10 Fix passing numpy quaternion insted of tf quaternion
    [hexapod_controller.py]
2018-05-10 Fix equation for rotating a vector
    [hexapod_ik_driver.py]
2018-05-10 Remove commencted out pi var and fix laser position
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2018-05-10 Optionally only publish odometry as msg and not to tf
2018-05-10 Fix syntax for private param
    [hexapod_controller.py]
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2018-05-11 Fix reading the wrong property and wrong datatype
    [hexapod_controller.py]
2018-05-12 Add limit breaks to hopper controller to prevent going over max vel
    [hexapod_controller.py]
2018-05-12 Prevent division by zero exception on short steps
    [hexapod_gait_engine.py]
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2018-05-13 Prevent resending of the same messaage so it won't interrupt nav cmd vel
2018-05-13 Add merger for odometry and update config for DWA planner
2018-05-14 Update odom merger to merge correct topics and types
    [hexapod_controller.py]
2018-05-14 Firx bug with calling field on a float
    [hexapod_controller.py]
2018-05-14 Start odometry merger to prevent imediate exit
2018-05-14 Fix incorrectly assigning yaw to x insted of z
    [hexapod_controller.py]
2018-06-01 Add new legs models
    [hopper_leg_femur.stl, hopper_leg_tibia.stl]
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2018-06-03 Update controller to use velocities insted of distances
2018-06-03 Add system for moving from uneven legs positions without dragging feet
2018-06-03 Move legs based on step time insted of by speed
2018-06-03 Fix step time calculation
    [hexapod_gait_engine.py]
2018-06-03 Undo rotation shortcut since it doesn't save anything
    [hexapod_gait_engine.py]
2018-06-03 fix incorrectly passed and calculated cycle length
    [hexapod_gait_engine.py]
2018-06-03 Move lidar and camera into a separate launch file
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2018-06-05 Replace tibia model with shorter legs
    [hopper_leg_tibia.stl]
2018-06-05 Fix math domain error in case acos is out of limits
    [hexapod_ik_driver.py]
2018-06-05 Use dynamixel script to fix angle limits
    [dynamixel_diagnostic_tool.py]
2018-06-05 Add script for reverting hexapod
    [servo_id_remapper.py]
2018-08-03 Create separate motor cotnrol into a new node
2018-08-04 Separate dynamixel driver to separate node and create proxy
    [hopper_leg_femur.stl]
2018-08-04 Fix typo in method name
    [body_controller_node.py]
2018-08-05 Fix wrong name of property
    [body_controller_node.py]
2018-08-05 Add latching for motor commands to ensure they are applied
2018-08-05 Disable ros sigterm listener to prevent topics from shutting down
    [body_controller_node.py, hexapod_controller.py]
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2018-08-06 Prevent erros from sending on a closed topic
    [hexapod_controller.py]
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2018-08-10 Switch to new message format and use yaml config file
2018-08-11 Revert "Cast hopper config types from strings"
    This reverts commit a60612150538dfaa52548cd94274bade6ea7dc83.
    [body_controller_node.py, hexapod_ik_driver.py]
2018-08-11 Fix writing to one motor twice
    [body_controller_node.py]
2018-08-11 fix command building which was reusing coxa id twice
    [body_controller_node.py]
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2018-08-11 Update steam controller to exit in case of an error
2018-08-11 Update read service to read all motors at the same time
2018-08-11 Fix class name in import
    [ik_proxy_controller.py]
2018-08-11 Return leg_pos message instead of motor read message
2018-08-11 FIx wrong assignment and ignoring request message
    [ik_controller_node.py]
2018-08-12 Remove leg goal positions class and refactor joints state publisher to use them
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2018-08-12 Add shebang and fix typo
    [hopper_leg_position_reader_node.py]
2018-08-12 Fix sequence and duration
    [hopper_leg_position_reader_node.py]
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2018-08-18 Fix missing bracket
2018-08-18 Fix correction from meters to cm
    [hexapod_controller.py]
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2018-08-18 Print dxl comm errors on dynamixel IO error
    [dynamixel_driver.py]
2018-08-18 Use with for locking to prevent exception from freezing system
    [body_controller_node.py]
2018-08-19 Add error messages to dynamixel exceptions
    [dynamixel_driver.py, dynamixel_error_helper.py]
2018-08-19 Allow message publisher to stop after a flag is flipped
    [hexapod_controller.py, ik_controller_node.py, joint_state_publisher.py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]
2018-08-19 Make camera nodes reset until working and decrease framerate
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2018-08-19 Fix no selected leg bug
2018-08-19 FIx leg selection system
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2018-08-19 Fix single leg mode leg selection
    [hexapod_gait_engine.py]
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2018-08-19 Change how base lifted vector for single leg works
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2018-08-19 Invert y on single leg mode
2018-08-19 Update single leg mode to relax legs correctly and have bigger range
    [hexapod_controller.py, hexapod_gait_engine.py]
2018-08-20 Fix issue with robot going in and out of single leg mode
    [hexapod_gait_engine.py]
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2018-08-20 Fix feet lifting and moving back down after single leg mode is disabled
    [hexapod_gait_engine.py]
2018-08-20 Fix wrong method name
    [hexapod_gait_engine.py]
2018-08-20 Fix issue with cancel move not working
    [hexapod_gait_engine.py]
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2018-08-21 Check telemetrics for 1 motor at a time only to prevent slowdowns
    [body_controller_node.py]
2018-09-18 Add fixed library for rock 64
    [dynamixel_functions.py]
2018-10-09 Update voltage monitor to ensure it won't trigger on local minimum
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2018-11-19 FIx bug and make trnasitions smoother
    [face_controller.py]
2018-11-21 Add new reset system and more animations
    [face_controller.py]
2018-11-27 Add cycle lenght and lift height for relaxing legs
2018-12-06 UPdate tibia lenght to shorter legs
    [hexapod.yaml]
2018-12-08 Add models, urdf and params for old model
    [hopper_leg_coxa.stl, hopper_leg_femur.stl, hopper_leg_tibia.stl]
2018-12-08 Add new model for hopper 2.0
    [hopper_leg_coxa.stl, hopper_leg_femur.stl, hopper_leg_tibia.stl]
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2018-12-11 Update sad emote to prevent breaking of relaxed pose
    [hexapod_ik_driver.py]
2018-12-11 Fix leg used during left hand wave
2018-12-15 Add face tracking with good features and optical flow
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2018-12-16 Fix bug with camera not moving
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2018-12-16 FIx typo in word idle
    [face_controller.py]
2018-12-17 Fix missing self and wrong enumeration of keys
    [face_controller.py]
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2018-12-17 Fix color names and go back to random after face tracking is off
    [face_controller.py]
2018-12-17 Allow for late color switching in breathing anymation
2018-12-23 Fix duplicate method names
    [face_controller.py]
2019-01-11 Use cobs encoding for serial protocol for LED face
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2019-03-23 Fix leg movement directions
    [folding_manager.py]
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2019-03-23 Update leg unfold procedures to prevent leg collisions
    [folding_manager.py]
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2019-03-23 FIx legs unfolding to a different degree
    [folding_manager.py]
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2019-03-23 Fix hopper not knowing correct leg positions aafter unfold
    [hexapod_gait_engine.py]
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2019-03-23 Fix folding leg condition
    [folding_manager.py]
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2019-03-24 Add rospy shutdown checks to prevent blocking on shutdown
    [face_controller.py]
2019-03-24 Repeat low voltage warning if voltage too low
2019-03-26 Add imu reader for new face and imu unit
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2019-03-31 Fix repeat low voltage messages and add repeat warning for critical
2019-03-31 Update the imu to read accel and rot data and init covariance matrix to unknown
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2019-03-31 Fix imu data stream
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2019-04-01 Fix repeat messages about battery level
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2019-04-01 Fix imu odometry math to not constantly update
    [odometry_publisher.py]
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2019-04-02 Add temporary odometry publishing for mid step motion
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2019-04-03 Update odometry estimateion and reduce cycle time multiplication
2019-04-03 Fix imu data in case topic hasn't been publisher yet
    [odometry_publisher.py]
2019-04-04 Fix misspelling of telemetrics to telemetry
    [body_controller.py, body_controller_node.py, telemetry_updater.py]
2019-04-21 Fix imu publisher exiting loop on malformed message
    [face_controller.py]
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2019-04-21 Fix repeated typo in word xacro
    [hopper.xacro, old_hopper.xacro]
2019-04-22 Update orientation of IMU
    [hopper.xacro]
2019-04-22 Fix reference to unkonw property
    [odometry_publisher.py]
2019-04-22 Publisher imu orientation
    [hopper.xacro]
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2019-05-22 Maek sure strings are in lower and cut to 6 characters
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2019-07-04 Remove repeat say battery level critical in case of a voltage drop
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2019-07-04 Fix passing lambda instead of a value
    [face_controller.py]
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2019-07-05 Move joint state publisher to body driver node to allow join states to be published even on direct joint movements
2019-07-06 Fix wrong init and add test script
    [leg_controller.py]
2019-07-06 Add feet sensors, remove old files and update motion test script
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2019-07-06 Add tf link for feet sensor
    [hopper.xacro]
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2019-07-15 Add service for moving until collision
    [hexapod_ik_driver.py, leg_controller.py]
2019-07-15 FIx base link visualizer
    [feet_sensor_visualizer.py]
2019-07-15 Fix marker frame time issue
    [feet_sensor_visualizer.py]
2019-07-15 Fix passing leg positions instead of desired vector
    [leg_controller.py]
2019-07-15 Fix move body core service
    [hexapod_gait_engine.py, leg_controller.py]
2019-07-15 Fix missing global reference
    [leg_controller.py]
2019-07-15 REvert direction of core movement
    [hexapod_ik_driver.py, leg_controller.py]
2019-07-15 Fix ik offsets being imprecise
    [hexapod.yaml]
2019-07-15 Fix ik offsets in incorrect direction
    [hexapod.yaml]
2019-07-16 Fix bug with feet sensor markers not showing
    [feet_sensor_visualizer.py]
2019-07-16 Update laser scanner node to be more precise
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2019-07-17 FIx item not itterable
    [leg_controller.py]
2019-07-17 Fix rotation issues for leg control
    [hexapod_ik_driver.py, leg_controller.py]
2019-07-18 Fix rotations for all services
    [leg_controller.py]
2019-07-19 Remove relative positioninng that doesn't apply for relative motions
    [leg_controller.py]
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2019-07-19 PAss the correct position to move function
    [leg_controller.py]
2019-07-20 Fix addition and subtraction overloads for LegPositions
    [hexapod_ik_driver.py, leg_controller.py]
2019-07-28 Fix lidar position
    [hopper.xacro]
2019-07-28 Update urdf to use model with lidar and shrink size of axes in rviz
    [hopper.xacro]
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2019-07-29 Add move legs relative until collision
    [leg_controller.py]
2019-07-29 Fix wrong class type as empty service
    [hexapod_controller.py]
2019-07-30 Move octomapping to map frame to allow slam navigation
2019-07-30 Fix move relative until hit
    [leg_controller.py]
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2019-07-30 FIx frame reference
2019-07-30 Fix frame translation
2019-07-30 Fix direction of translation
    [leg_controller.py]
2019-07-31 Update all leg services to use LegPositions message
2019-07-31 Ignore if feet are touching ground for first 90 percent of the move
2019-07-31 Fix not updating leg height
    [hexapod_gait_engine.py]
2019-07-31 Calculate fraem time correctly
    [hexapod_gait_engine.py]
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2019-07-31 Fix step done checking logic
    [hexapod_gait_engine.py]
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2019-08-07 Fix height and odom error
    [hexapod_controller.py]
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2019-08-14 Switch to using loc instead of cloc because Rust <3
2019-09-21 Add image of hopper cad as link to cad
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2020-01-13 Add unit file exports and remove touch buttons
2020-05-04 Switch to UDP communication with the rust controller
2020-05-10 Fix wrong future module name
    [ik_UDP_controller.py]
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
